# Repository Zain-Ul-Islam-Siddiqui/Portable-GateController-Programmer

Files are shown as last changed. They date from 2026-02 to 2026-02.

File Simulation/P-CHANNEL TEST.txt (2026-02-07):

$ 1 0.000005 10.20027730826997 50 5 43 5e-11
f 400 240 448 240 33 1.5 0.02
r 448 160 448 112 0 470
r 384 192 432 192 0 1000000
r 256 240 208 240 0 2200
s 336 208 336 160 0 1 false
s 96 320 96 272 0 1 false
r 96 208 96 160 0 100000
R 96 112 96 80 0 0 40 3.3 0 0 0.5
R 336 112 336 80 0 0 40 3.3 0 0 0.5
w 96 112 96 160 0
w 448 288 448 256 0
w 448 192 448 224 0
w 336 160 336 144 0
w 336 144 336 112 0
g 320 352 320 368 0 0
g 448 352 448 368 0 0
g 96 352 96 368 0 0
w 96 352 96 320 0
w 320 352 320 304 0
w 448 352 448 288 0
w 384 192 384 240 0
w 432 192 448 192 0
w 448 192 448 160 0
w 448 80 448 112 0
s 320 304 320 256 0 1 false
w 320 256 320 240 0
w 336 208 336 240 0
162 400 80 448 80 2 default-led 1 0 0 0.01
R 400 80 400 48 0 0 40 5 0 0 0.5
w 384 240 400 240 0
w 336 240 384 240 0
w 336 240 320 240 0
w 256 240 320 240 0
w 96 208 96 240 0
w 96 240 208 240 0
w 96 272 96 240 0

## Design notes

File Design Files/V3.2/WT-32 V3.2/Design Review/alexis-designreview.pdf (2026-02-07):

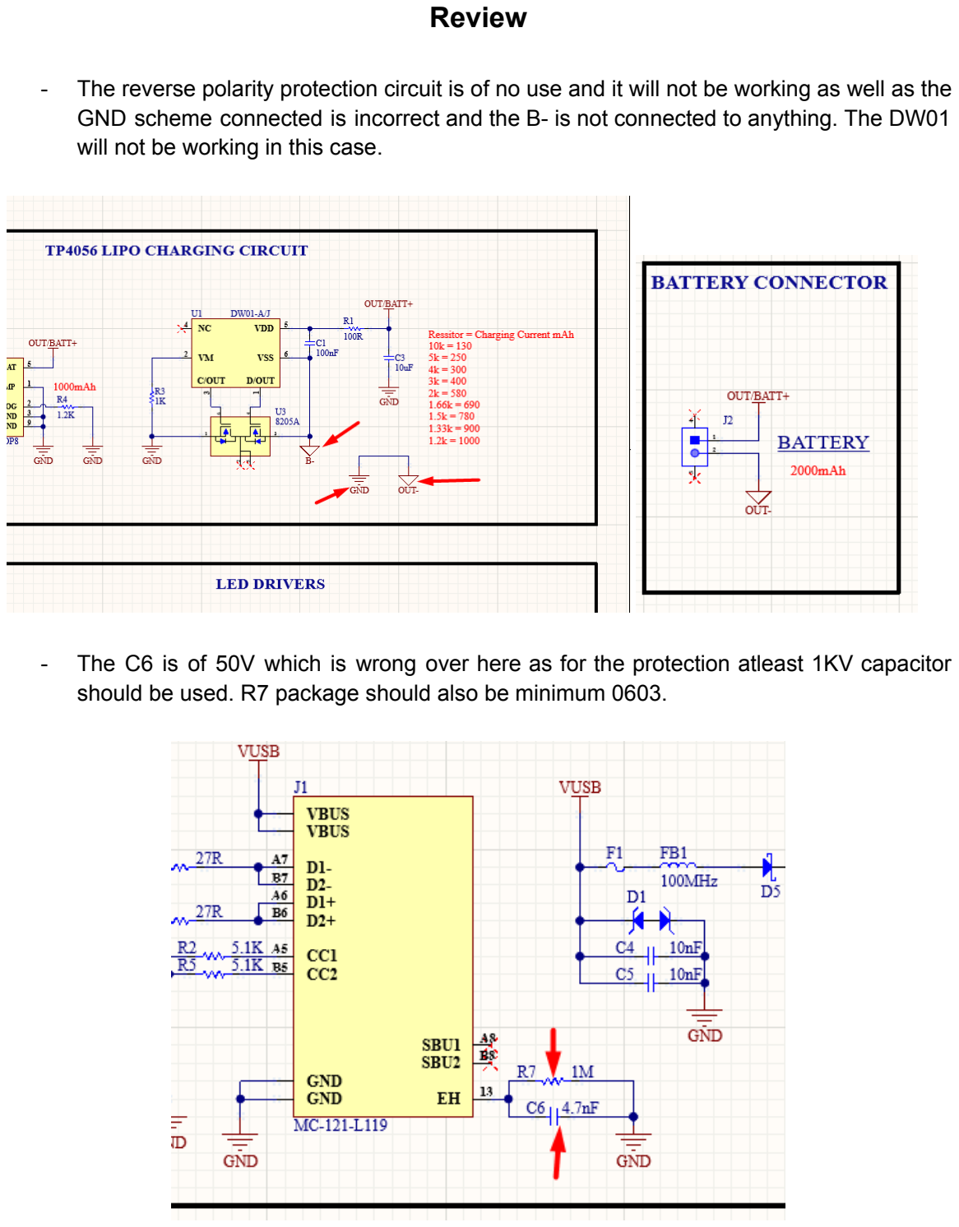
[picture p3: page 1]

### Review

- The reverse polarity protection circuit is of no use and it will not be working as well as the GND scheme connected is incorrect and the B- is not connected to anything. The DW01 will not be working in this case.
- The C6 is of 50V which is wrong over here as for the protection atleast 1KV capacitor should be used. R7 package should also be minimum 0603.

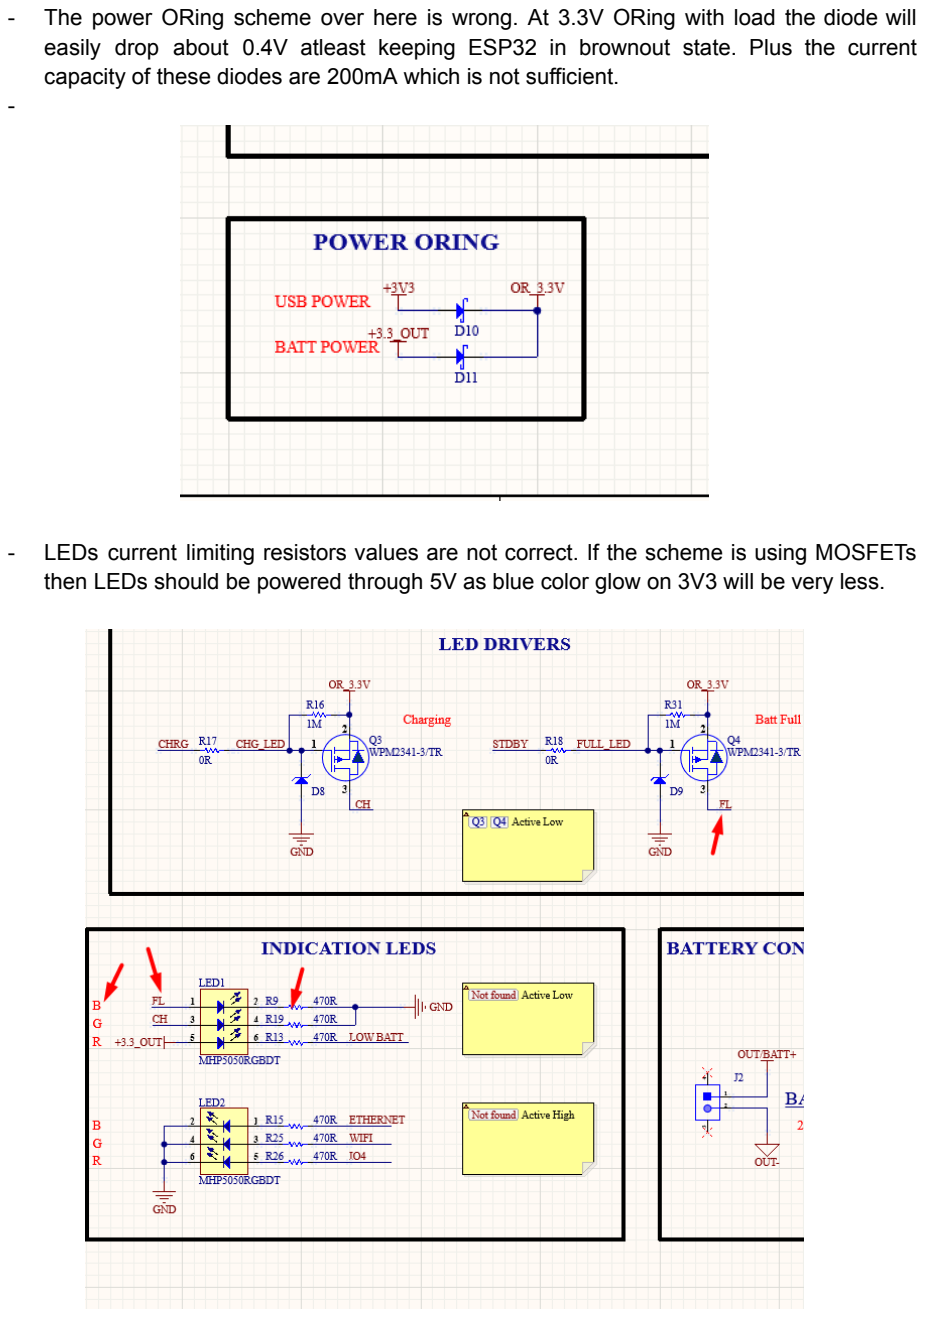
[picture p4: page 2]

- The power ORing scheme over here is wrong. At 3.3V ORing with load the diode will easily drop about 0.4V atleast keeping ESP32 in brownout state. Plus the current capacity of these diodes are 200mA which is not sufficient.
- LEDs current limiting resistors values are not correct. If the scheme is using MOSFETs then LEDs should be powered through 5V as blue color glow on 3V3 will be very less.

- Please confirm the battery connector pinout is correct as generally pin 1 is connected to GND.

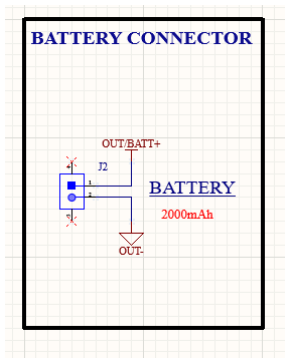
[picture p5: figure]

- Low battery cutoff might not be needed as we are using Fuel Gauge in this design. Even for the overdischarge protection, DW01 is already implemented.

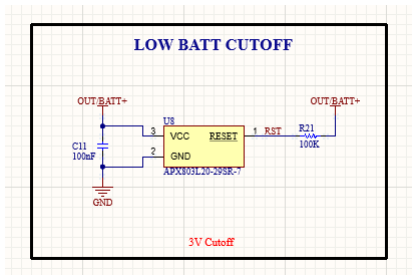
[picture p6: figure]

- C26 should not be used on IO0 as it will fail the USB auto download functionality.

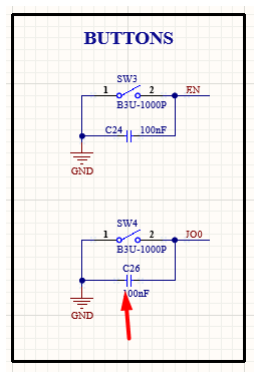
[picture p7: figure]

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
s it is

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
pin.

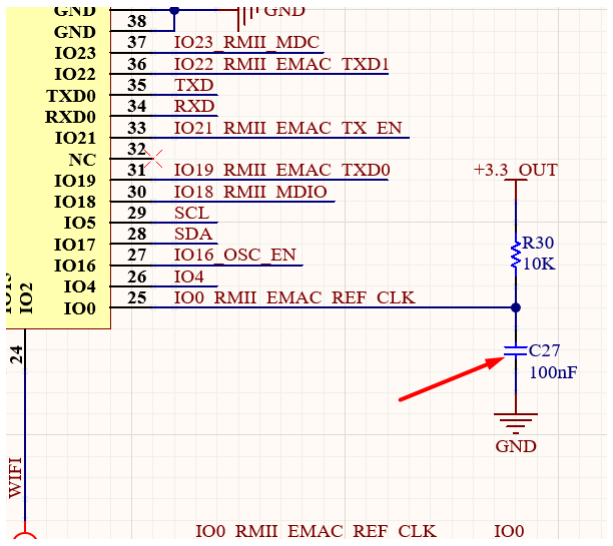
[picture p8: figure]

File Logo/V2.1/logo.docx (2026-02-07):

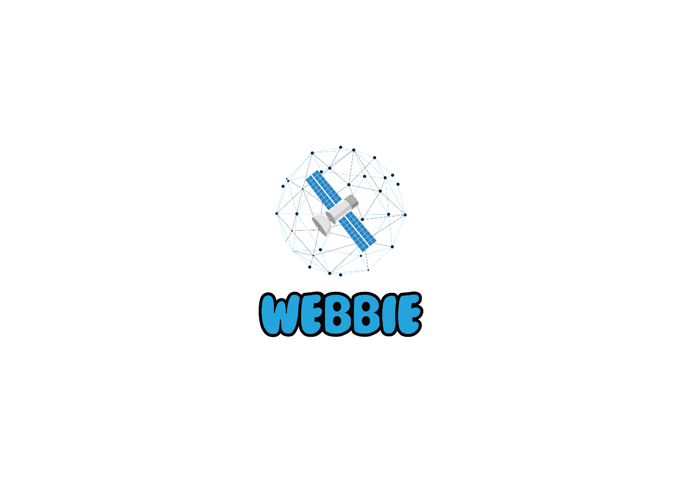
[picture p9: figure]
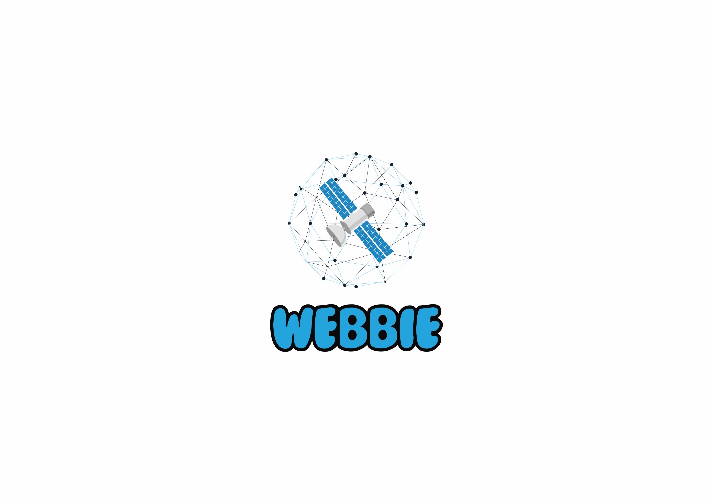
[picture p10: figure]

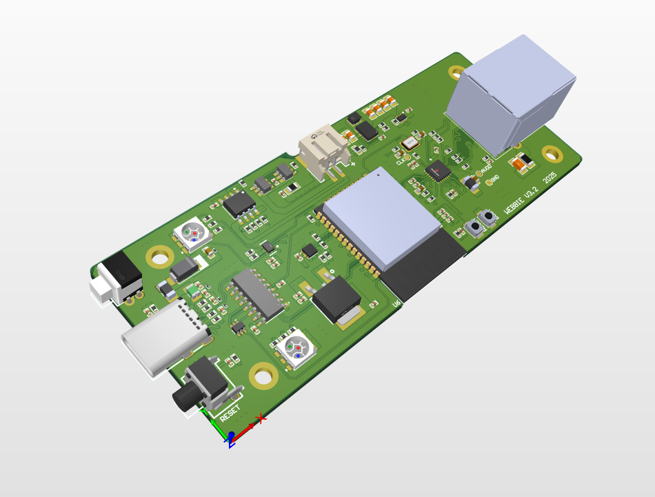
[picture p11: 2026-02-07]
Design Files/V3.2/WT-32 V3.2/Rendering/3D Isometric.png

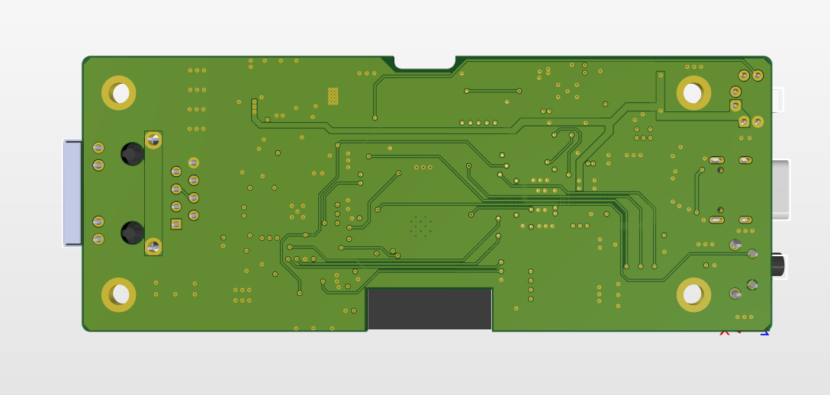
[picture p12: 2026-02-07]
Design Files/V3.2/WT-32 V3.2/Rendering/3D Bottom.png

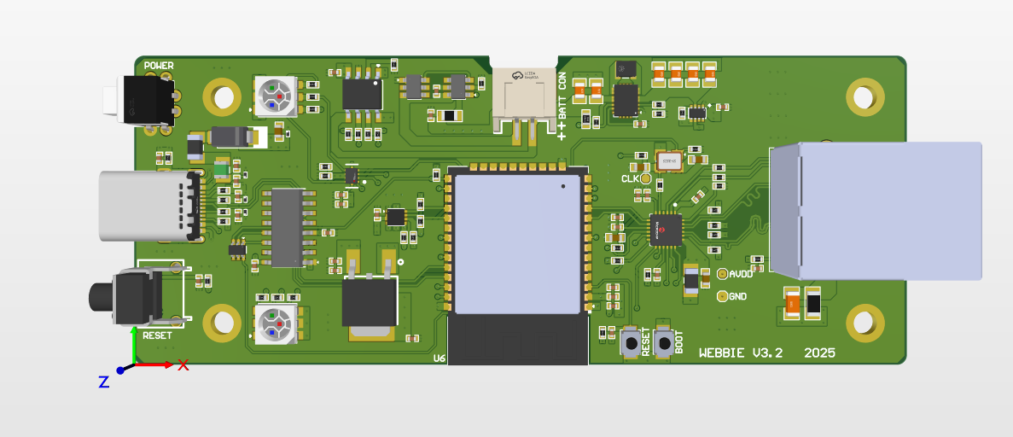
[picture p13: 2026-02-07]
Design Files/V3.2/WT-32 V3.2/Rendering/3D Top.png

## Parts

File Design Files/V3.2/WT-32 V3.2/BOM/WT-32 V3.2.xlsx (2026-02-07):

Designator | Comment | Footprint | LCSC Part Number | Manufacturer Part Number
C1, C2, C9, C10, C20, C22, C23, C24, C29, C31, C34, C35, C36, C41, C43 | 100nF | cap-0402 | C361198 | C1005X7R1H104KT000F
C3 | 10uF | Cap-0402 | C315248 | CL05A106MP5NUNC
C4, C5, C21, C28 | 10nF | Cap-0402 | C327025 | CC0402KRX7R8BB103
C6, C33, C39 | 4.7nF | Cap-0402 | C106208 | CC0402KRX7R9BB472
C7, C8, C11, C27, C32 | 1uF | Cap-0402 | C106254, C326568, C325464 | CC0402KRX5R6BB105, CC0402KRX5R8BB105, CC0402KRX5R7BB105
C12, C26, C30, C37 | 10uF | Cap-0603 | C96446 | CL10A106MA8NRNC
C13, C14 | 47pF | Cap-0402 | C393684 | GCM1555C1H470FA16D
C15, C16, C17, C18, C19, C25 | 22uF | Cap-0805 | C338080 | C2012X5R1V226MT000E
C40 | 4.7nF | Cap-1206 | C107198 | CC1206KKX7RCBB472
D1, D4, D6, D7 | PESD5V0H1BSFYL | DSN0603-2 | C477989 | PESD5V0H1BSFYL
D5 | SS34 | SMA | C8678 | SS34
F1 | BSMD0805L-200 | Fuse-0805 | C2757931 | BSMD0805L-200
FB1, FB2 | 100MHz | IND-1206 | C85841 | BLM31PG121SN1L
J1 | MC-121-L119 | MC-121-L119 | C6332278 | MC-121-L119
J2 | S2B-PH-SM4-TB(LF)(SN) | S2B-PH-SM4-TB(LF)(SN) | C295747 | S2B-PH-SM4-TB(LF)(SN)
J3 | HR911105A | HR911105A | C12074 | HR911105A
L1 | 1uH | IND-1008 (2520 Metric) | C882955 | DFE252012P-1R0M=P2
LED1, LED2 | MHP5050RGBDT | MHP5050RGBDT | C409780 | MHP5050RGBDT
R1 | 100R | RES-0805 | C138274 | AC0805FR-07100RL
R2, R5 | 5.1K | Res-0402 | C105872 | RC0402FR-075K1L
R3 | 1K | Res-0402 | C313354 | CRCW04021K00FKEDHP
R4 | 1.2K | Res-0402 | C138040 | RC0402FR-071K2L
R6, R8, R17, R18, R20, R21, R27, R30, R32, R33, R37, R39, R45, R49, R50 | 10K | Res-0402 | C60490 | RC0402FR-0710KL
R7 | 1M | Res-0402 | C144054 | AF0402JR-071ML
R9, R13, R15, R19, R25, R26, R40, R42 | 470R | Res-0402 | C114877 | RC0402FR-07470RL
R10, R11, R44 | 0R | Res-0402 | C106231 | RC0402FR-070RL
R14 | 768k | Res-0402 | C227223 | AC0402FR-07768KL
R16 | 10K | Res-0603 | C95204 | RT0603BRD0710KL
R22, R23 | 27R | Res-0402 | C138021 | RC0402FR-0727RL
R24 | 137k | Res-0402 | C5153963 | FRC0402F1373TS
R28, R29, R34, R35 | 49.9R | Res-0402 | C87044 | RC0402FR-0749R9L
R36 | 1.5K | Res-0402 | C114759 | RC0402FR-071K5L
R38, R41 | 33R | Res-0402 | C138002 | RC0402FR-0733RL
R43 | 12.1k | Res-0402 | C281773 | RT0402BRD0712K1L
R46 | 1M | Res-1206 | C108083 | RC1206FR-071ML
SW1 | TK-6580A8-1 | TK-6580A8-1 | C528772 | TK-6580A8-1
SW2 | 1-1825027-4 | 1-1825027-4 | C2928195 | 1-1825027-4
SW3, SW4 | B3U-1000P | B3U-1000P | C231329 | B3U-1000P
U1 | DW01-A/J | SOT-23-6 | C2909013 | DW01-A/J
U2 | TP4056-42-ESOP8 | ESOP-8 | C16581 | TP4056-42-ESOP8
U3 | 8205A | SOT-23-6 | C351449 | 8205A
U4 | UZ1085L-33-TN3-R | TO-252-2(DPAK) | C125622 | UZ1085L-33-TN3-R
U5 | TPS63020DSJR | 14-VSON (4x3) | C15483 | TPS63020DSJR
U6 | ESP32-WROOM-32E-N4 | 38-SMD Module | C701341 | ESP32-WROOM-32E-N4
U7 | UMH3N | SC-70-6_ | C62892 | UMH3N
U8 | LM66200DRLR | SOT8 | C3235556 | LM66200DRLR
U9 | CH340C | SOP-16 | C84681 | CH340C
U10 | LAN8720A-CP-TR | LAN8720A-CP-TR | C45223 | LAN8720A-CP-TR
U11 | MAX17048G+T10 | 8-TDFN-EP (2x2) | C2682616 | MAX17048G+T10
U12 | TS3A24157RSER | UQFN-10(1.5x2) | C575568 | TS3A24157RSER
X1 | 50MHz | OT2EL4C4JI-111OLP-50M | C5203552 | OT2EL4C4JI-111OLP-50M

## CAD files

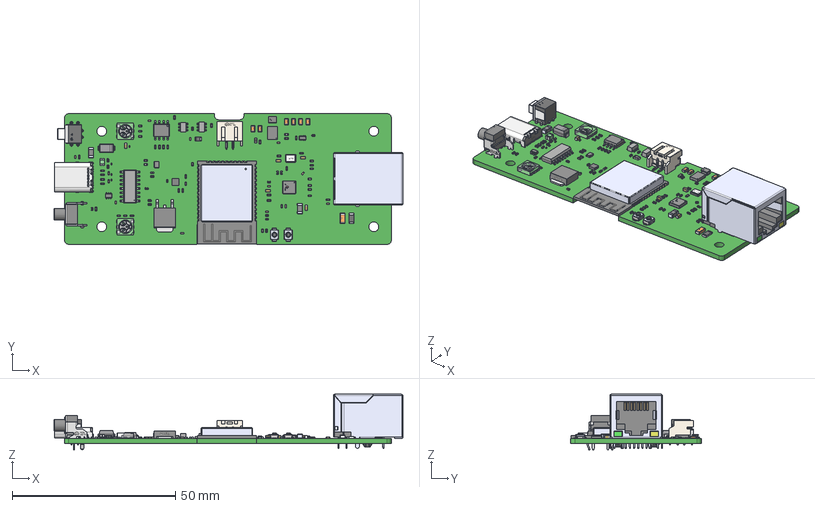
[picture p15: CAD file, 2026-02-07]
Design Files/V3.2/WT-32 V3.2/STEP 3D/Webbie-V3.2.step
106.8 x 40.0 x 17.0 mm
q3yF-Board
HR911105A_HR911105A
User Library-User Library-Siward_SX3225
Texas Logo Yury
Texas Logo Yury - Copy
21-0168E_T822-1_MXM
pads
Microchip logo
Microchip Logo 1
SO_18HDTR_STM
User Library-SC70-6
TPS63020DSJR--3DModel-STEP-1
21-0058I_MXM x 2
TP4056-42-ESOP8--3DModel-STEP-56544
User Library-OMRON B3U1000P x 2
User Library-RES_1005-0402 x 44
User Library-RESC1608X05N
User Library-CR3216-1206
User Library-CR2012-0805
LED SMD 5050 RGB x 2
VLS252012HBX-100M
BLM31PG121SN1L x 2
User Library-fuse0805L050WR
PESD5V0H1BSF x 4
User Library-DO-214AC SMA
User Library-Capacitor 0402 x 30
User Library-0805 SMD Capacitor x 6
User Library-1206 SMD Capacitor
User Library-CAPC1608X09 x 5
ESP32-WROOM-32E (16MB)--3DModel-STEP-269445
aZC3-SW1-SW-TH_1-1825027-4

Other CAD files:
Design Files/V3.2/WT-32 V3.2/DXF/Webbie-V3.0.DXF

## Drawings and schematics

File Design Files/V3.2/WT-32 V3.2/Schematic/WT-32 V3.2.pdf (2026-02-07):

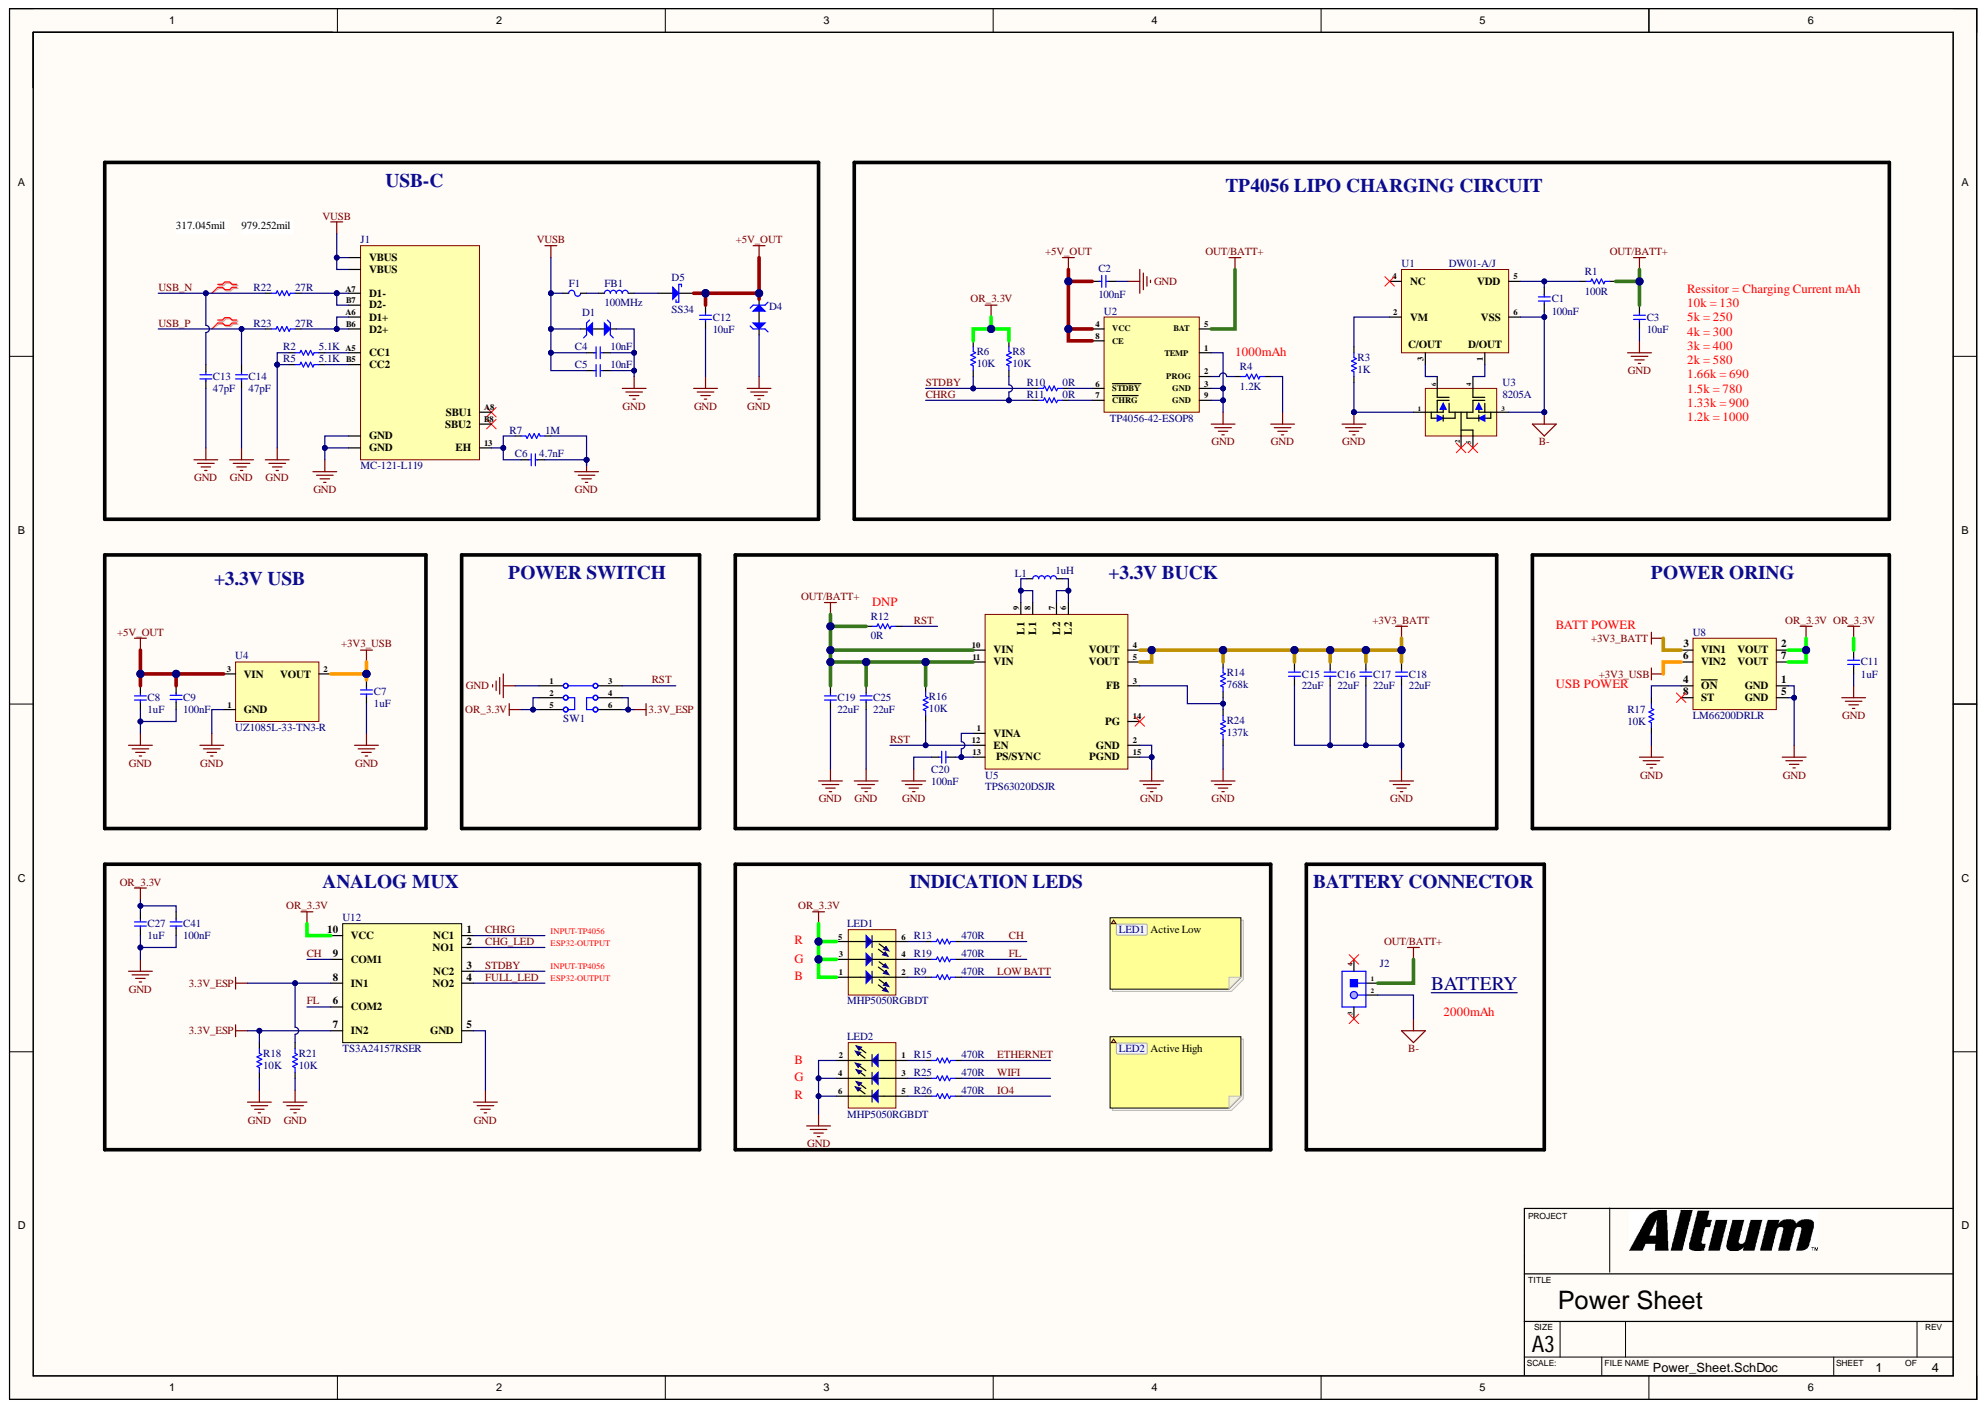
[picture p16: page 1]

SIZE | | | REV

SCALE: | FILE NAME | SHEET OF

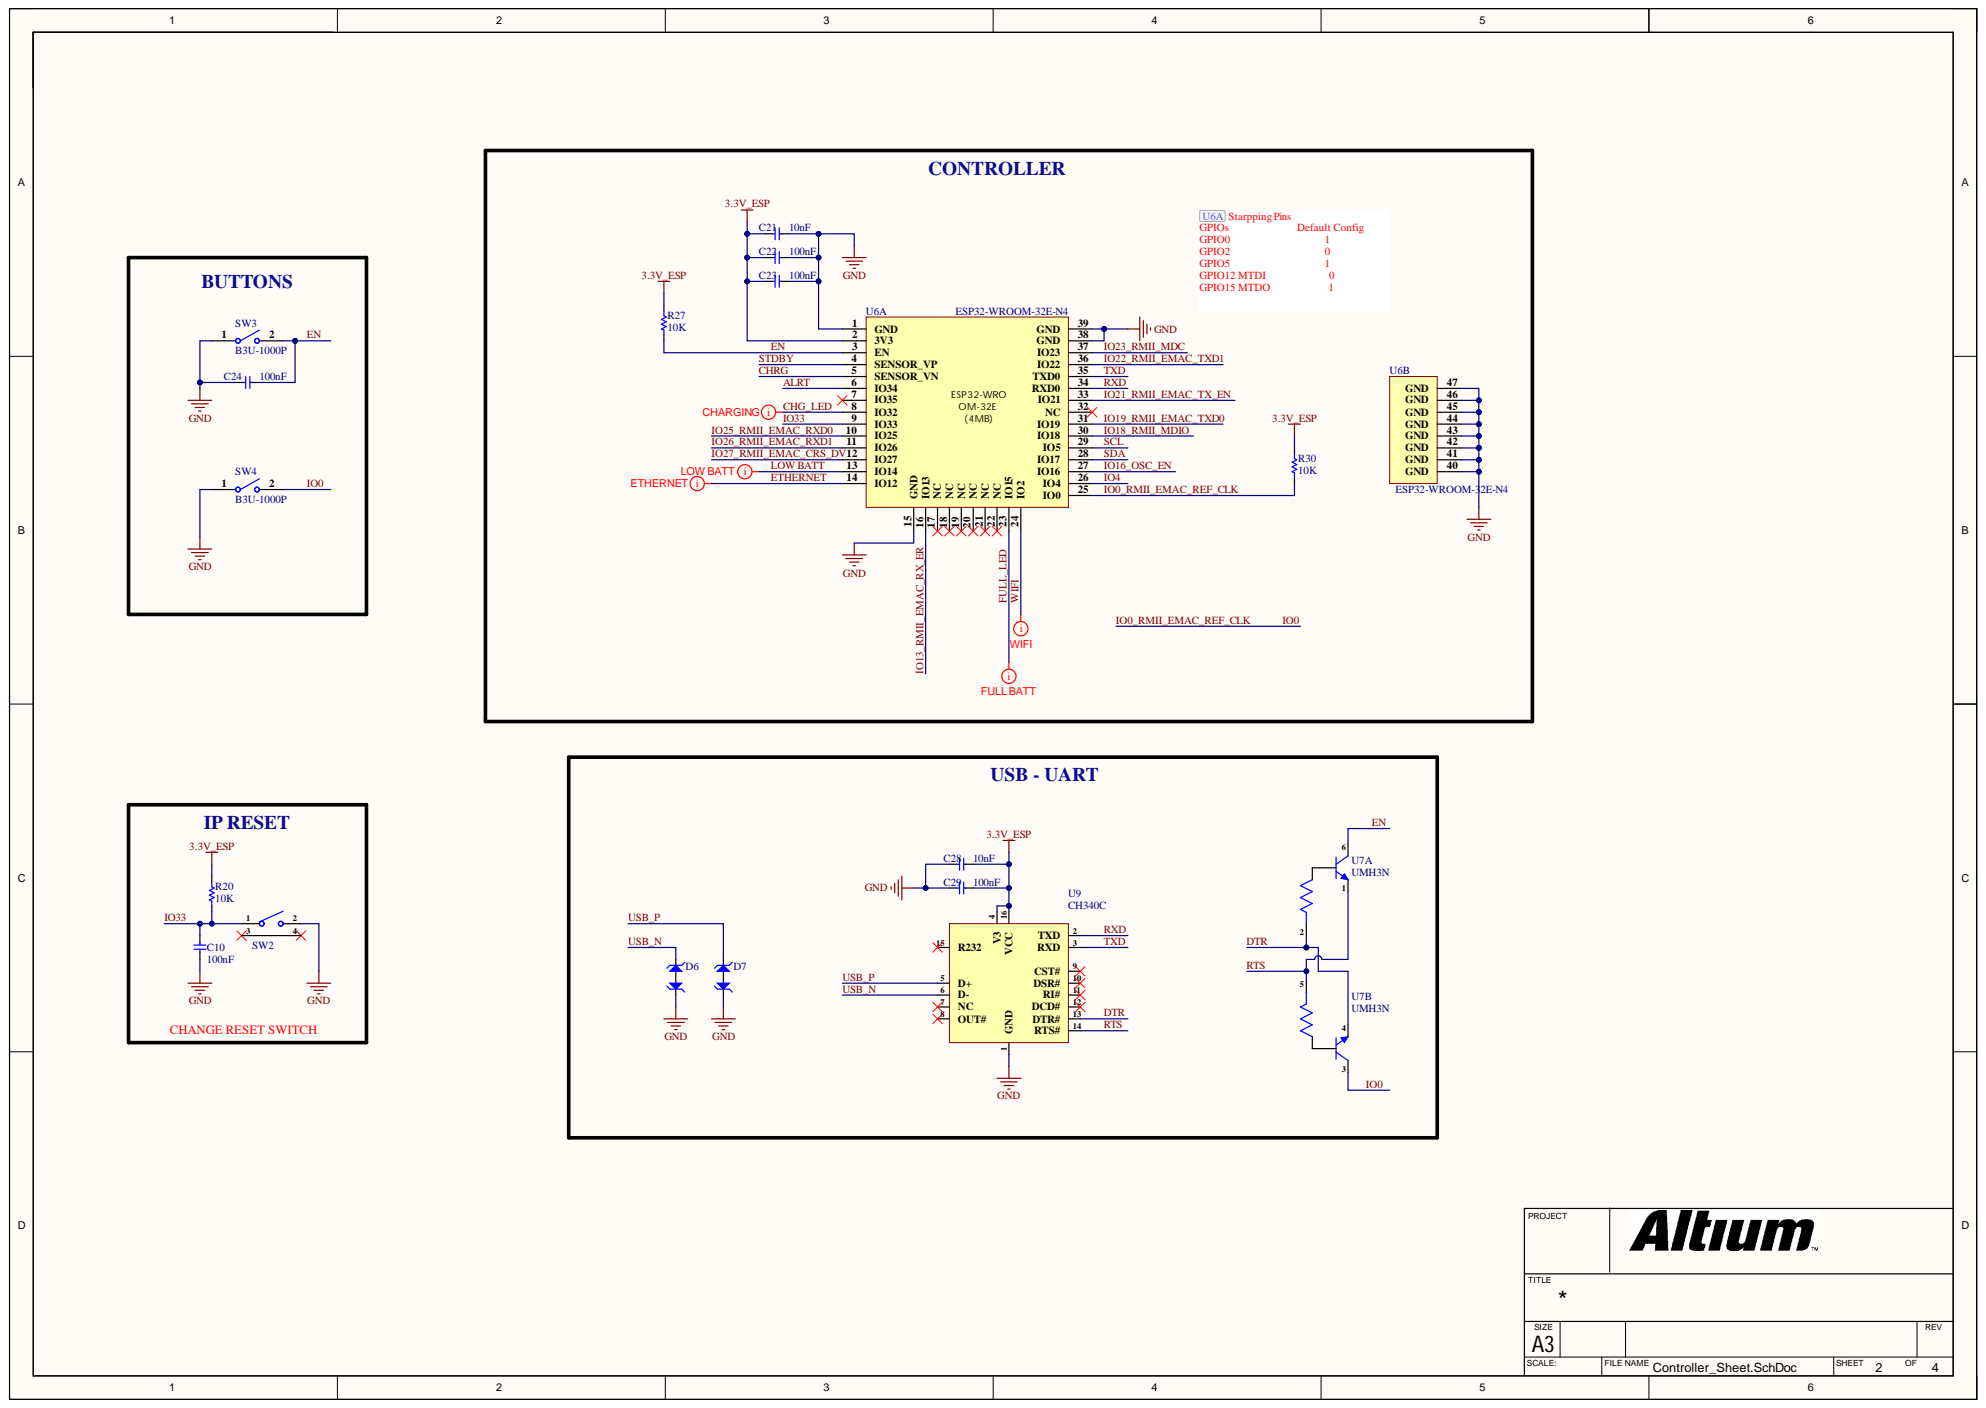
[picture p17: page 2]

GN D GN 3V3 EN SENSOR_V P SENSOR_V N IO3 4 IO3 5 E S P 3 2-WR O O M -32E IO3 2 IO3 3 ( 4 M B ) 5 10 IO2 IO2 6 7 12 IO2 4 13 IO1 2 14 IO1 | XD 1
2 | | IO23_RMII_M TX D

IO0_RMII_EMAC_REF_ CLK

SIZ E | | | RE V

SCA L E : | FIL E NA M E ntro l l er_Sh e et.Sc h D o c | SHE E T OF

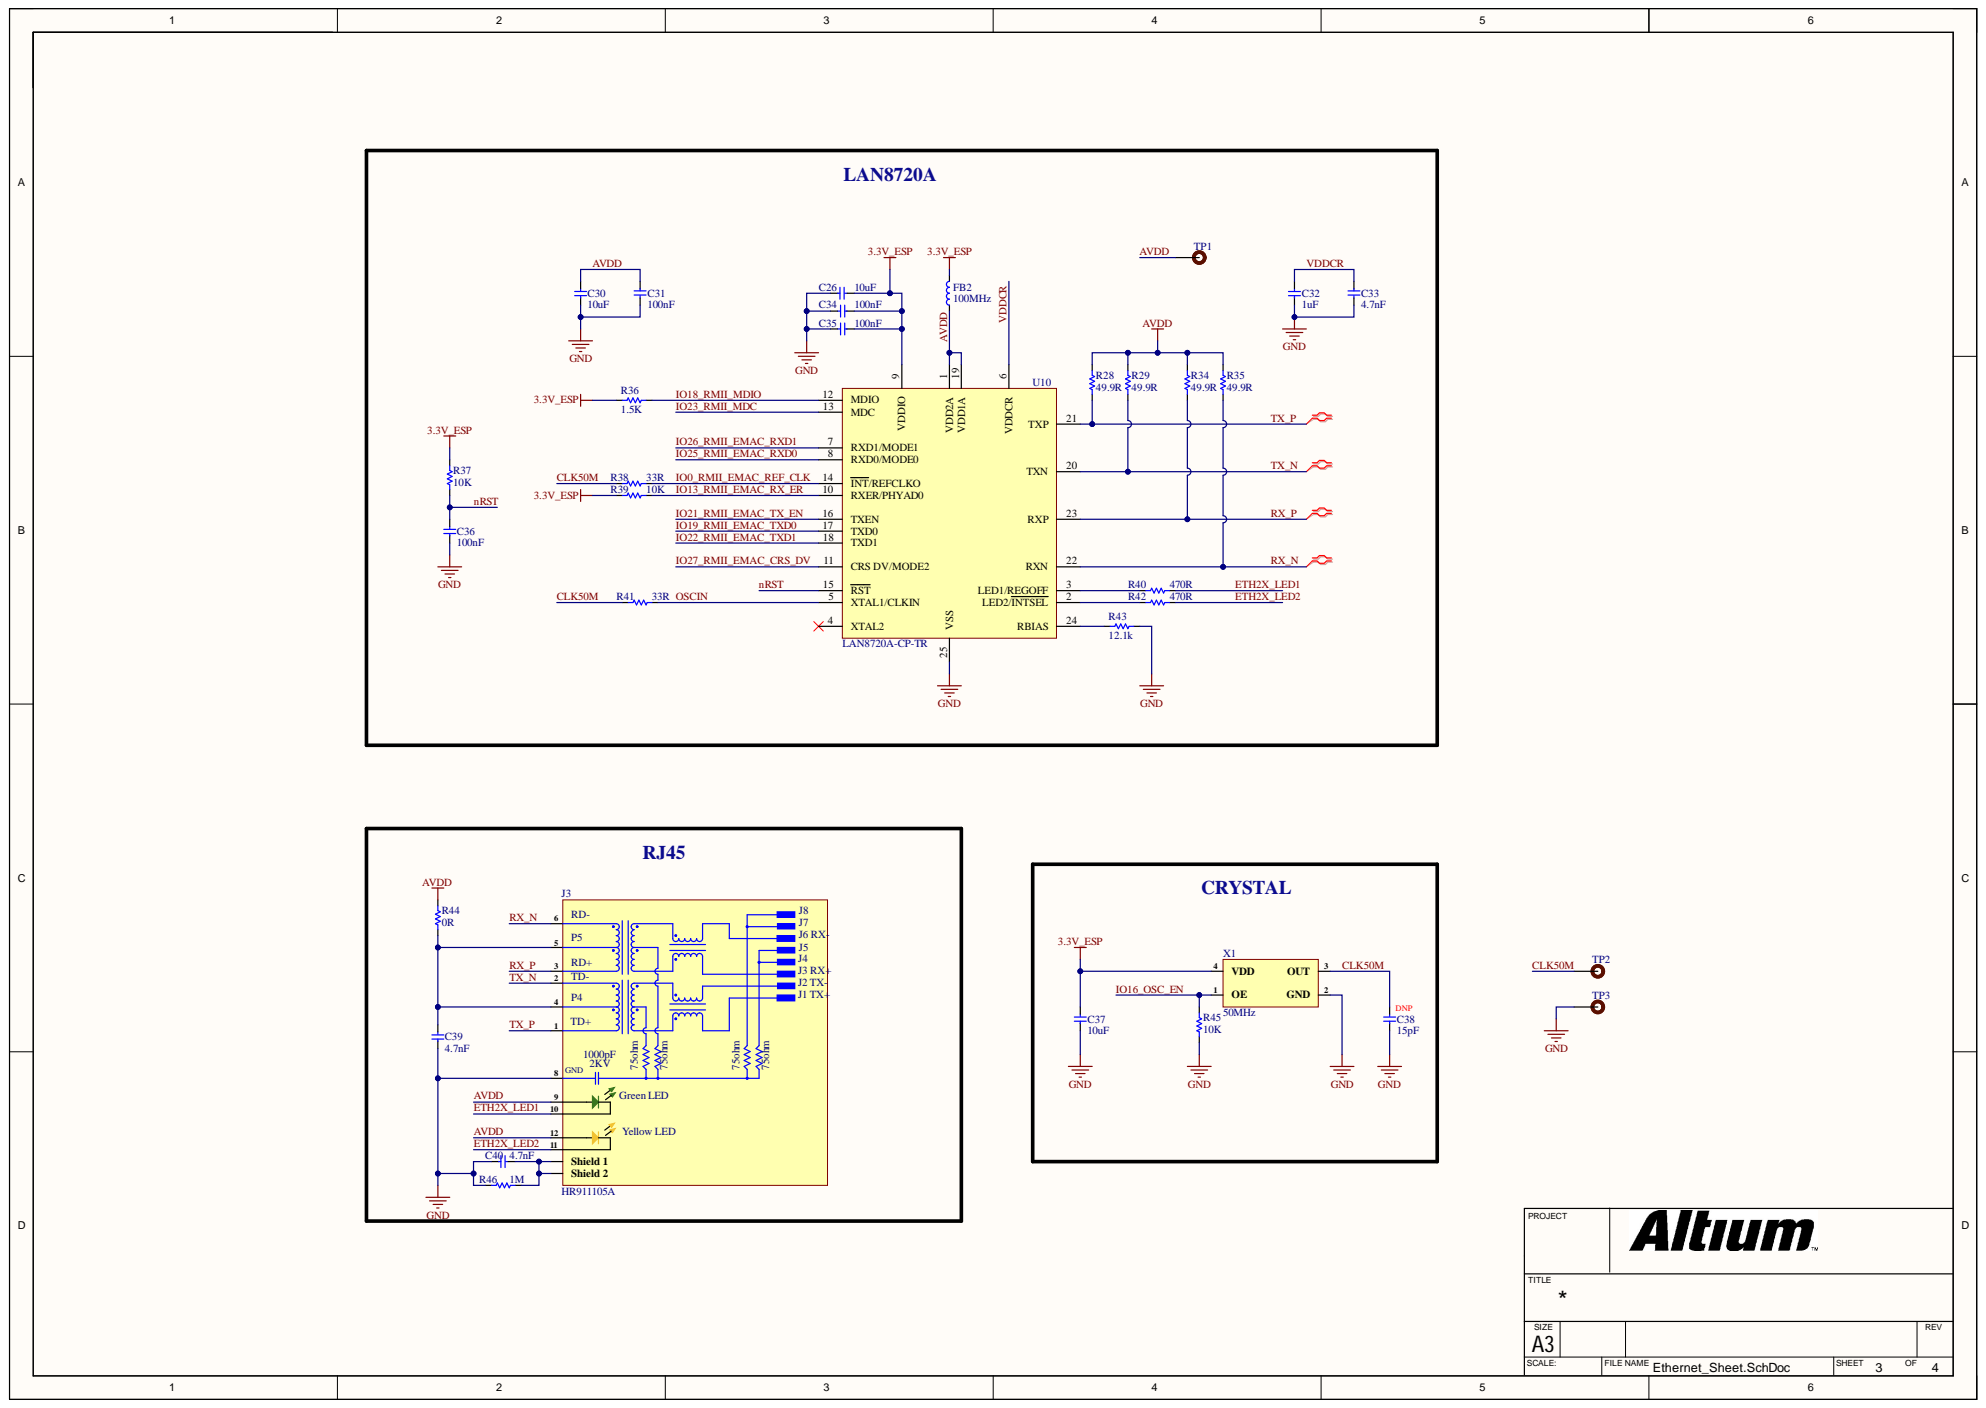
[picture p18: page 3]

Shield 1 Shield 2

SIZE | | | REV

SCALE: | FILE NAME | SHEET OF

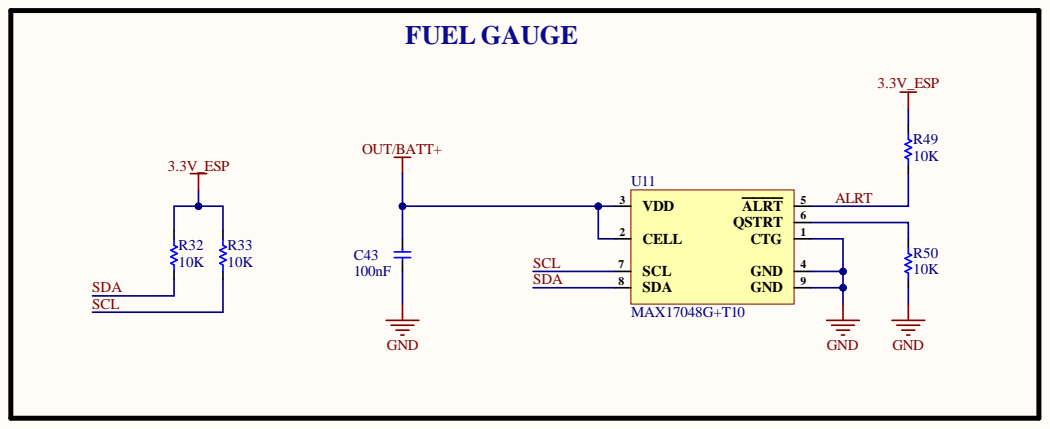
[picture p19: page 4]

SIZ E | | | RE V

SCA L E : | FIL E NA M E e l G a u g e _Sh e et.Sc h D o c | SHE E T OF

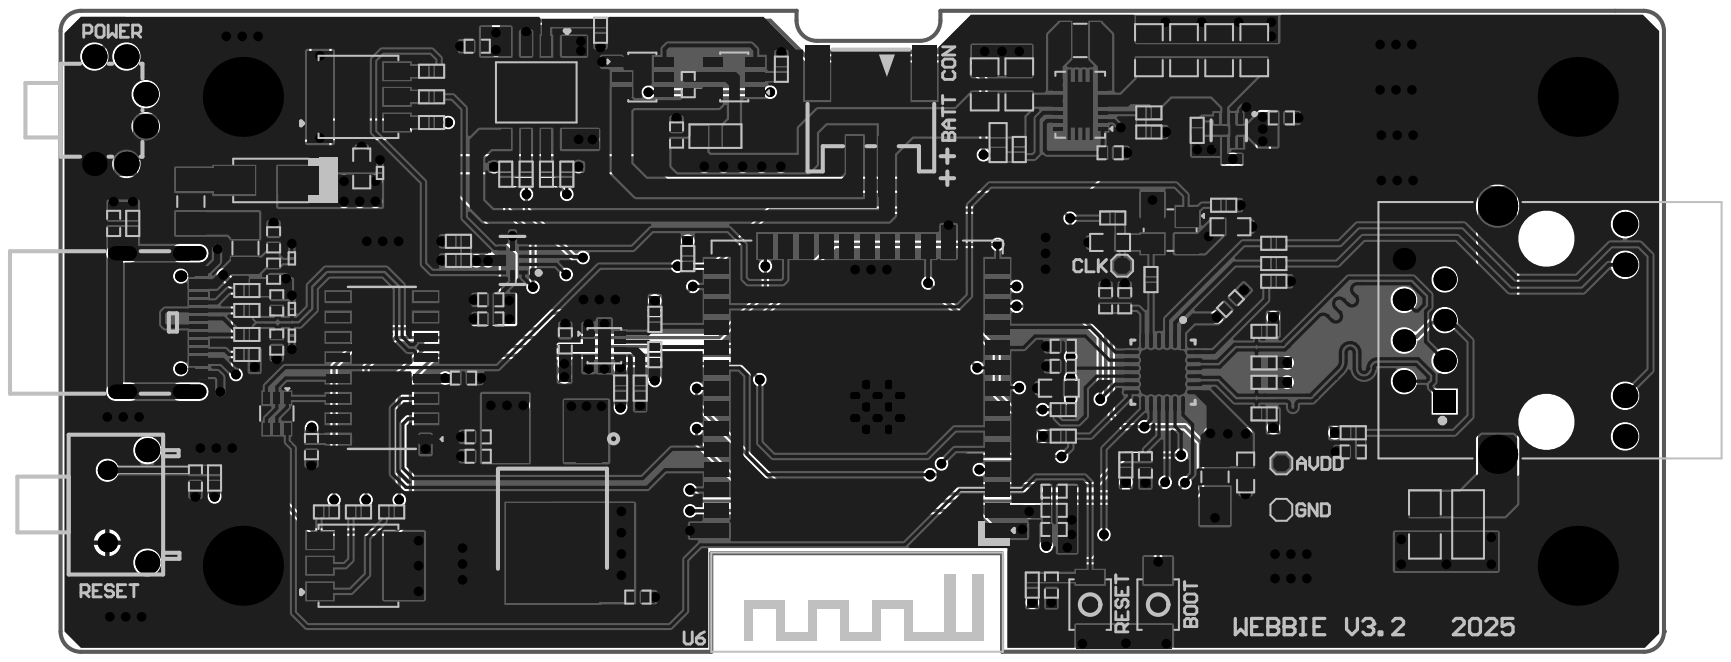
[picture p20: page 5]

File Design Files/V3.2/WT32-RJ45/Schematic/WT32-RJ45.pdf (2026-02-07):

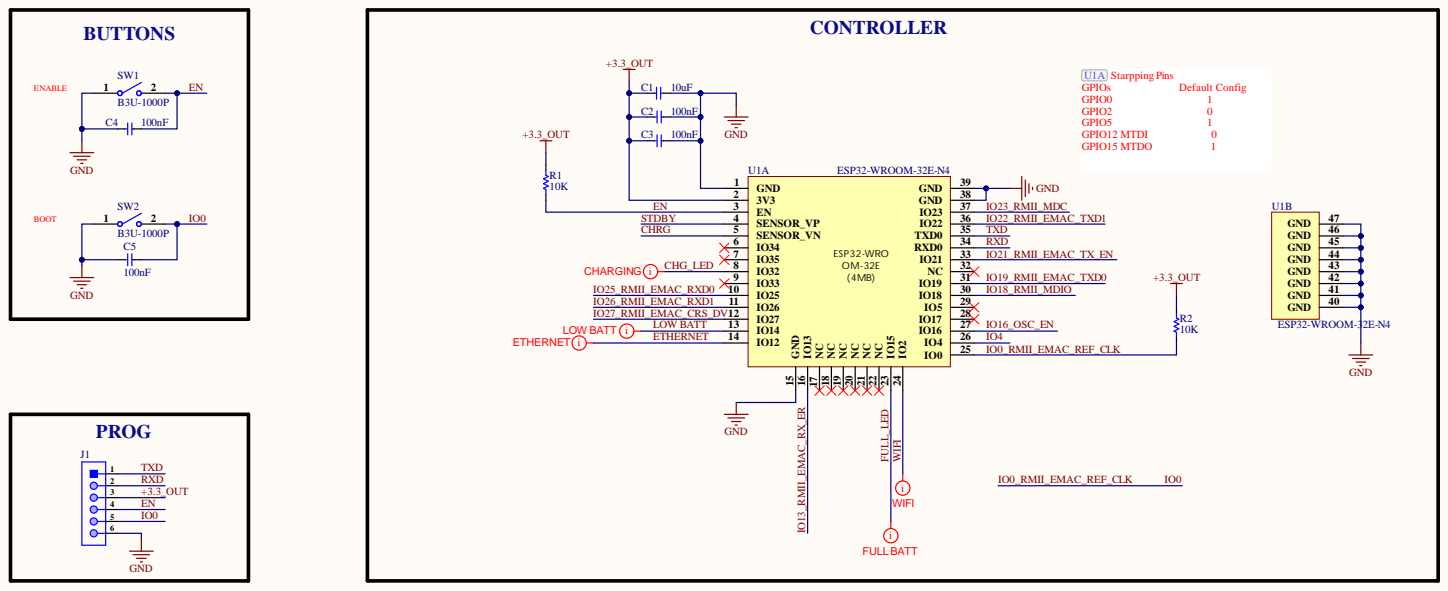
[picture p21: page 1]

2 | | IO23_RMII_M

SIZ E | | | RE V

SCA L E : | FIL E NA M E 2.Sc hDo c | SHE E T OF

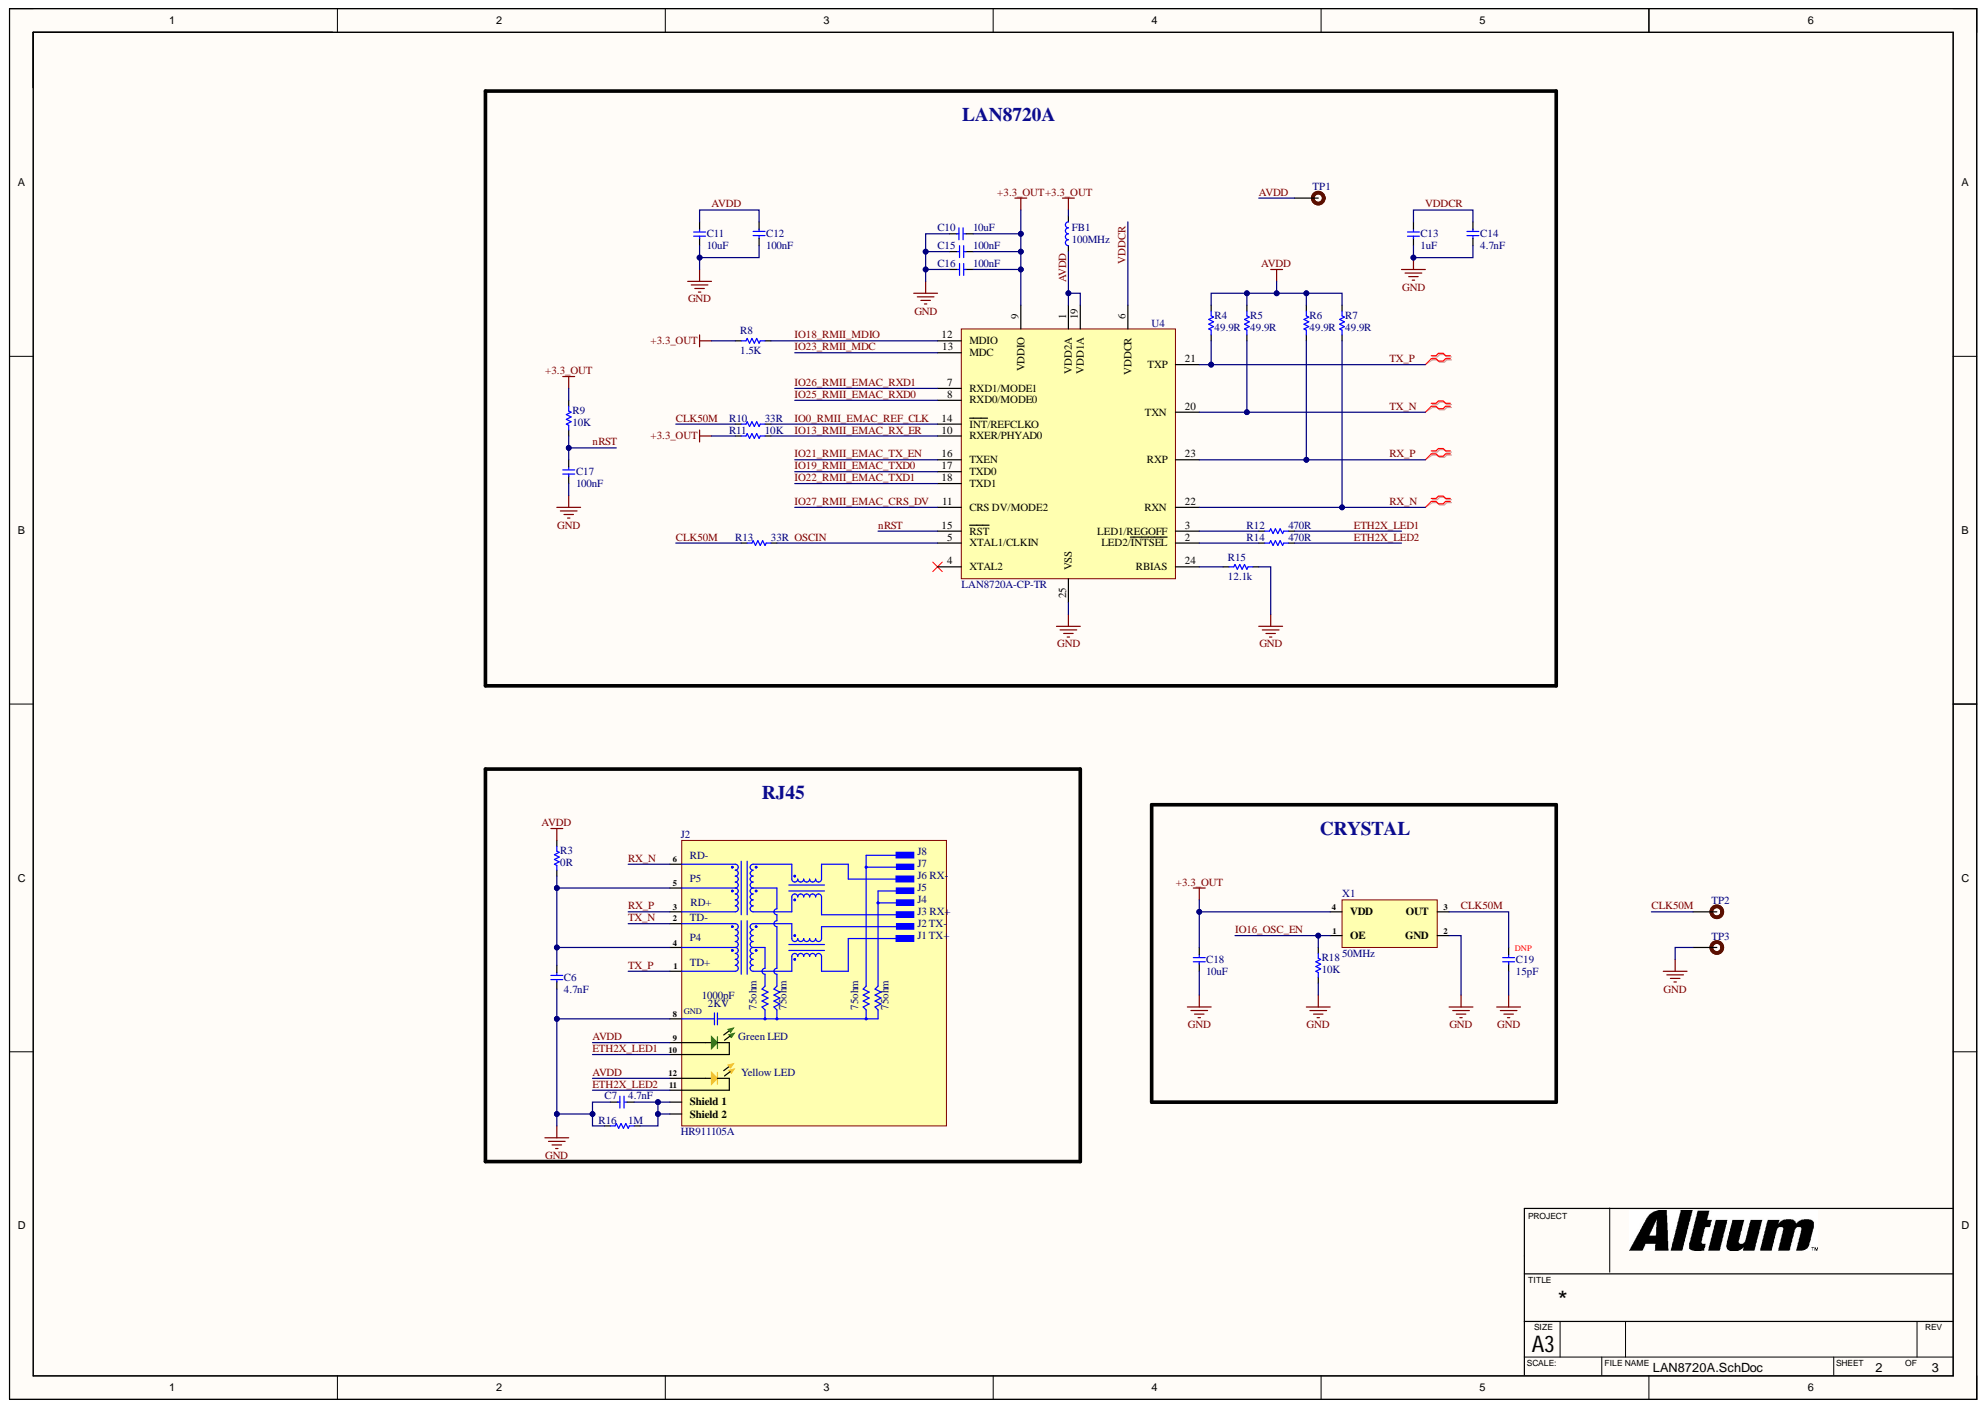
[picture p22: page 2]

SIZE | | | REV

SCALE: | FILE NAME | SHEET OF

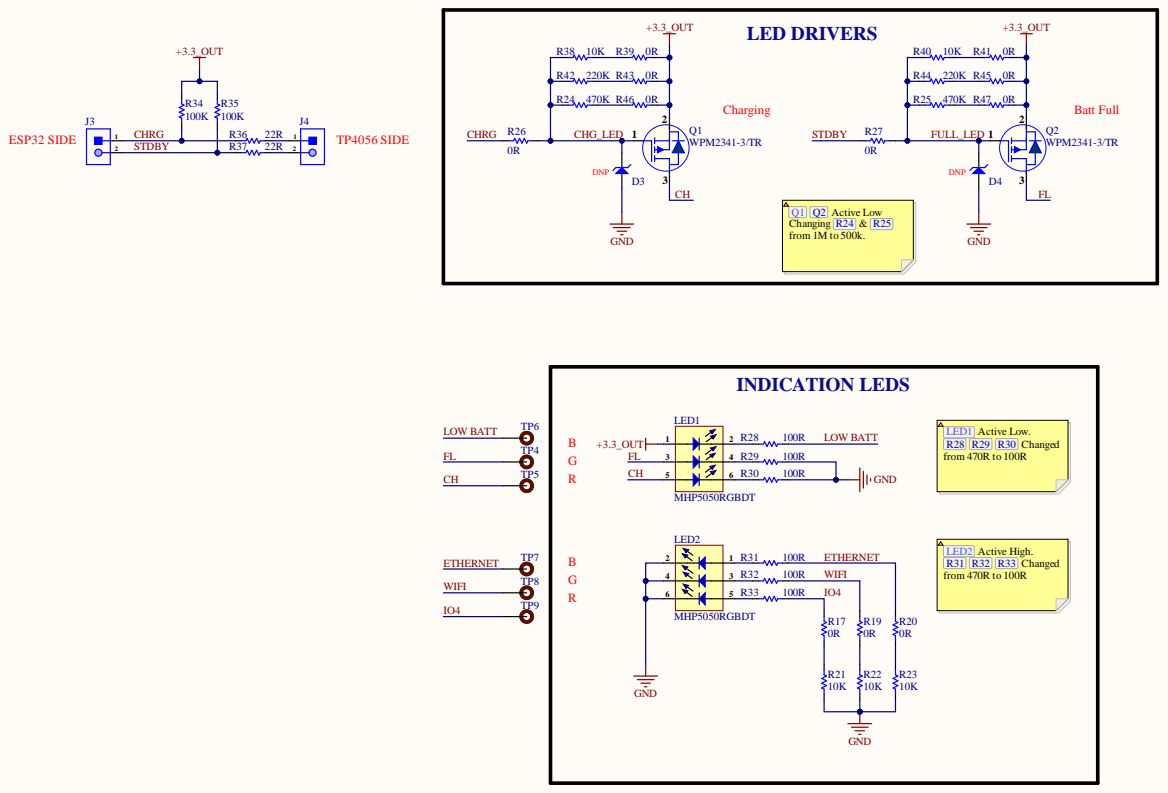
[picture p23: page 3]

SIZE | | | REV

SCALE: | FILE NAME | SHEET OF

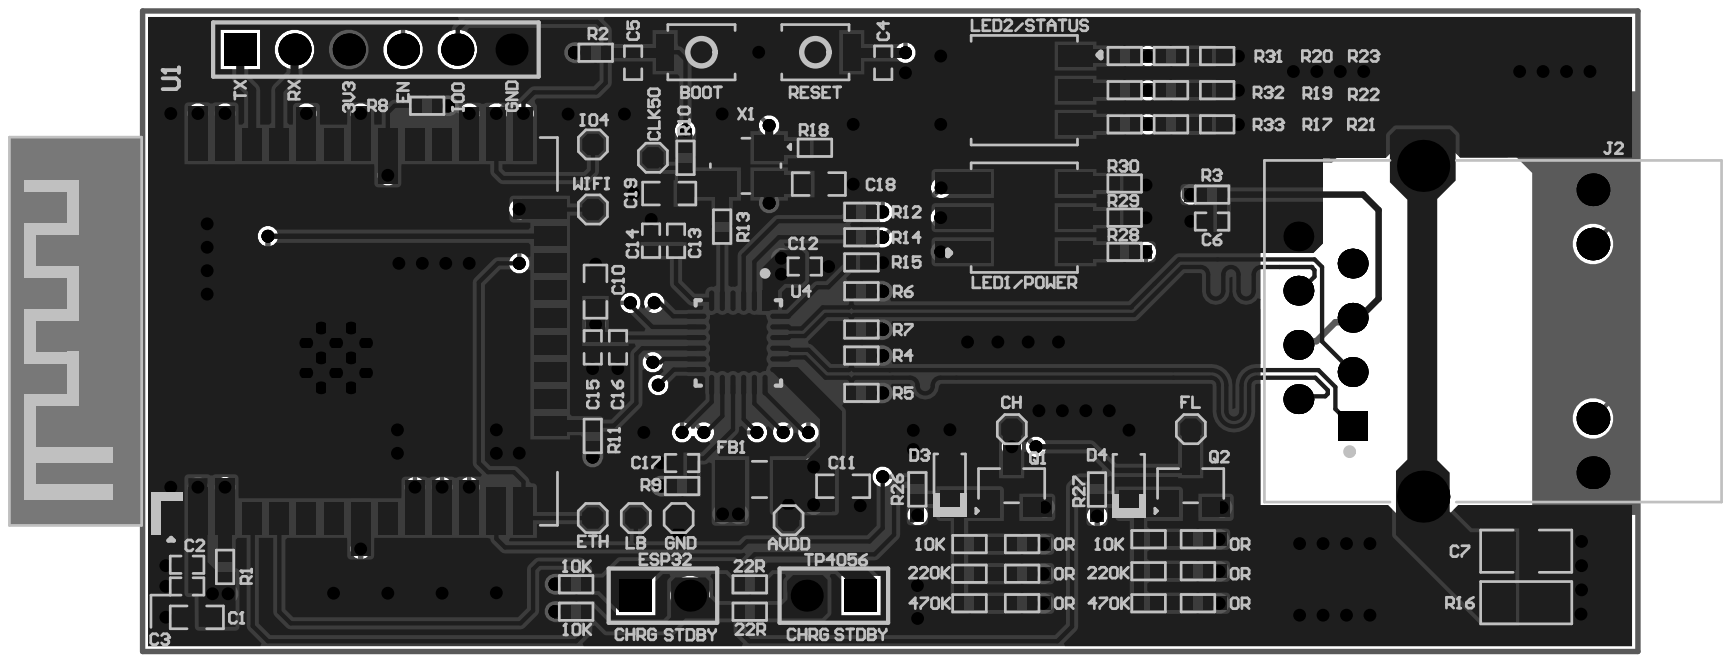
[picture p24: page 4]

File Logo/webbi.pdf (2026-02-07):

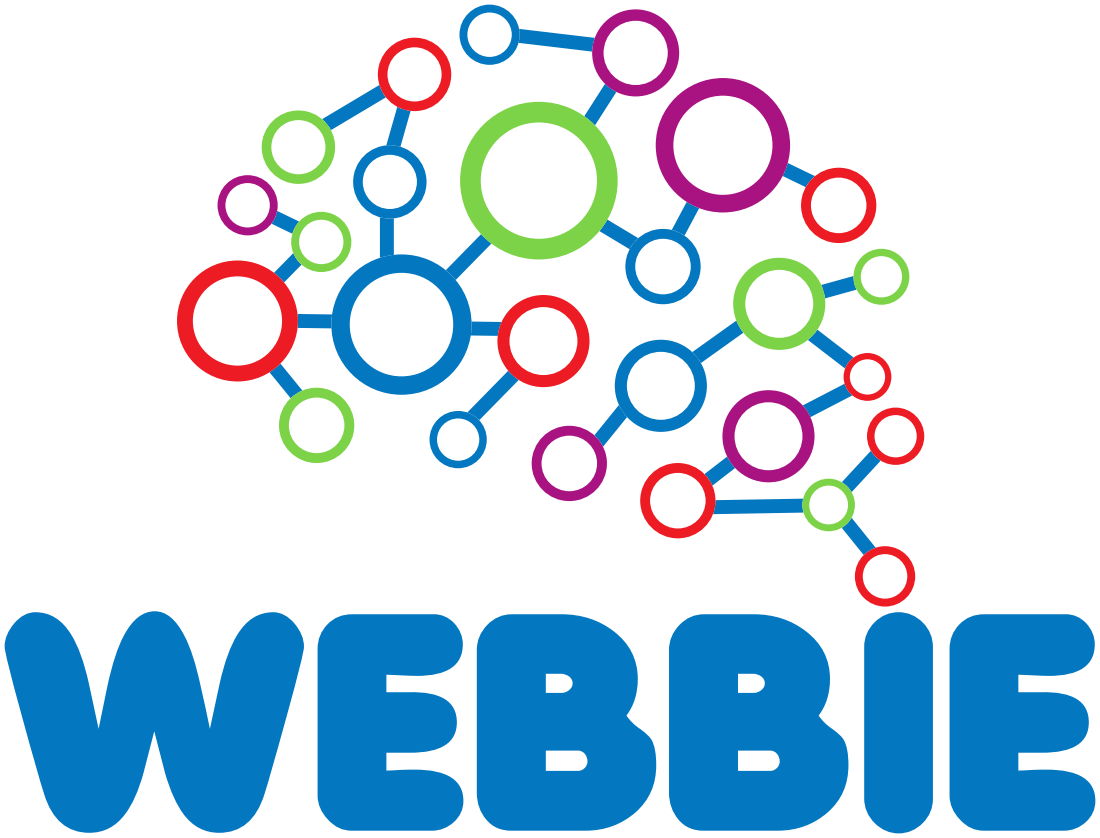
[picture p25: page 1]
WEBBIE

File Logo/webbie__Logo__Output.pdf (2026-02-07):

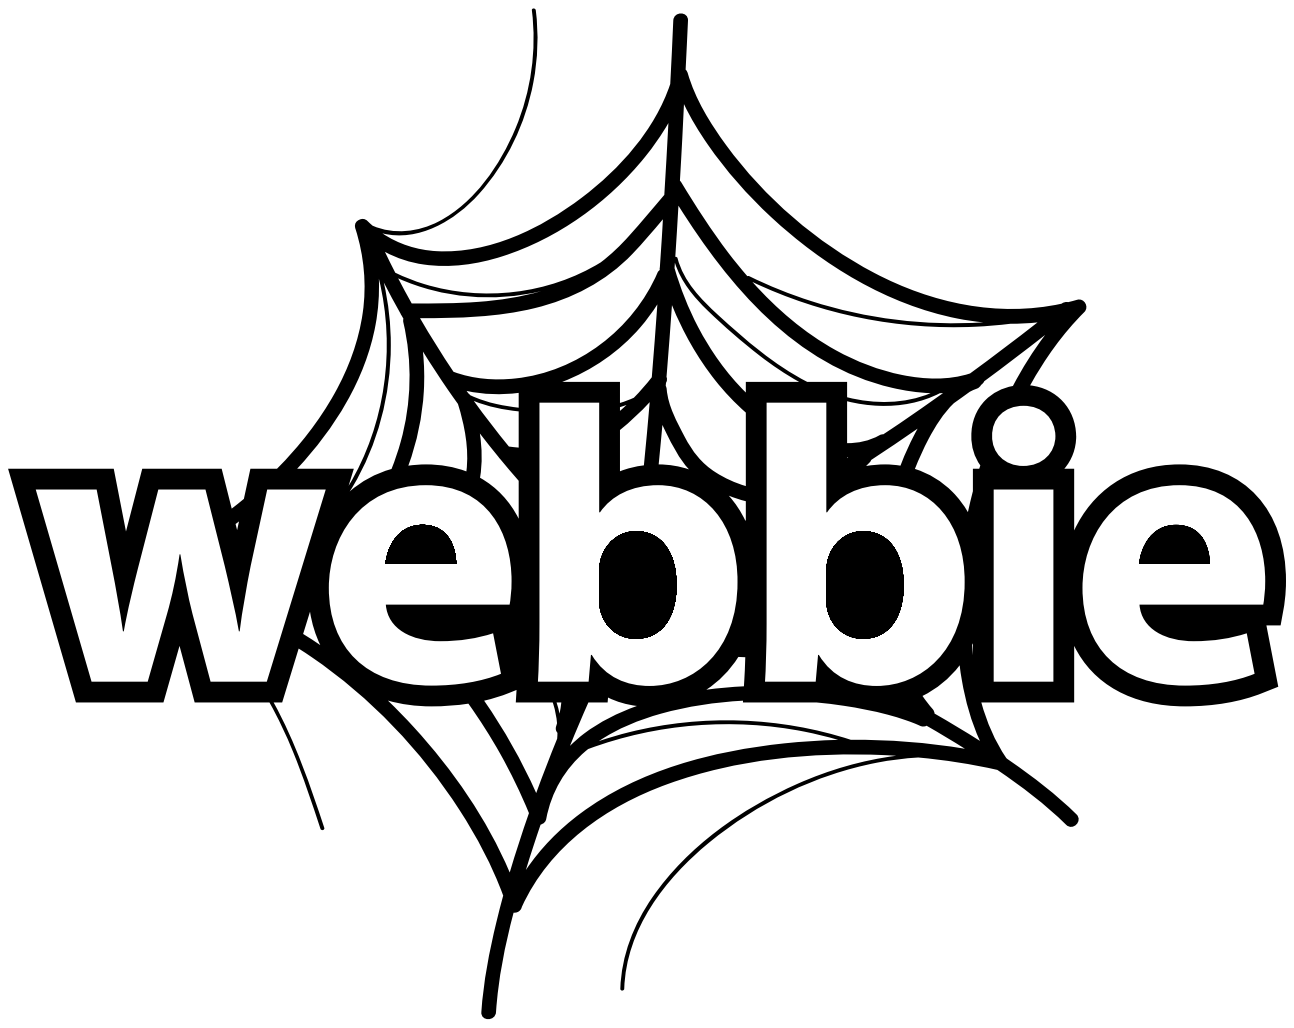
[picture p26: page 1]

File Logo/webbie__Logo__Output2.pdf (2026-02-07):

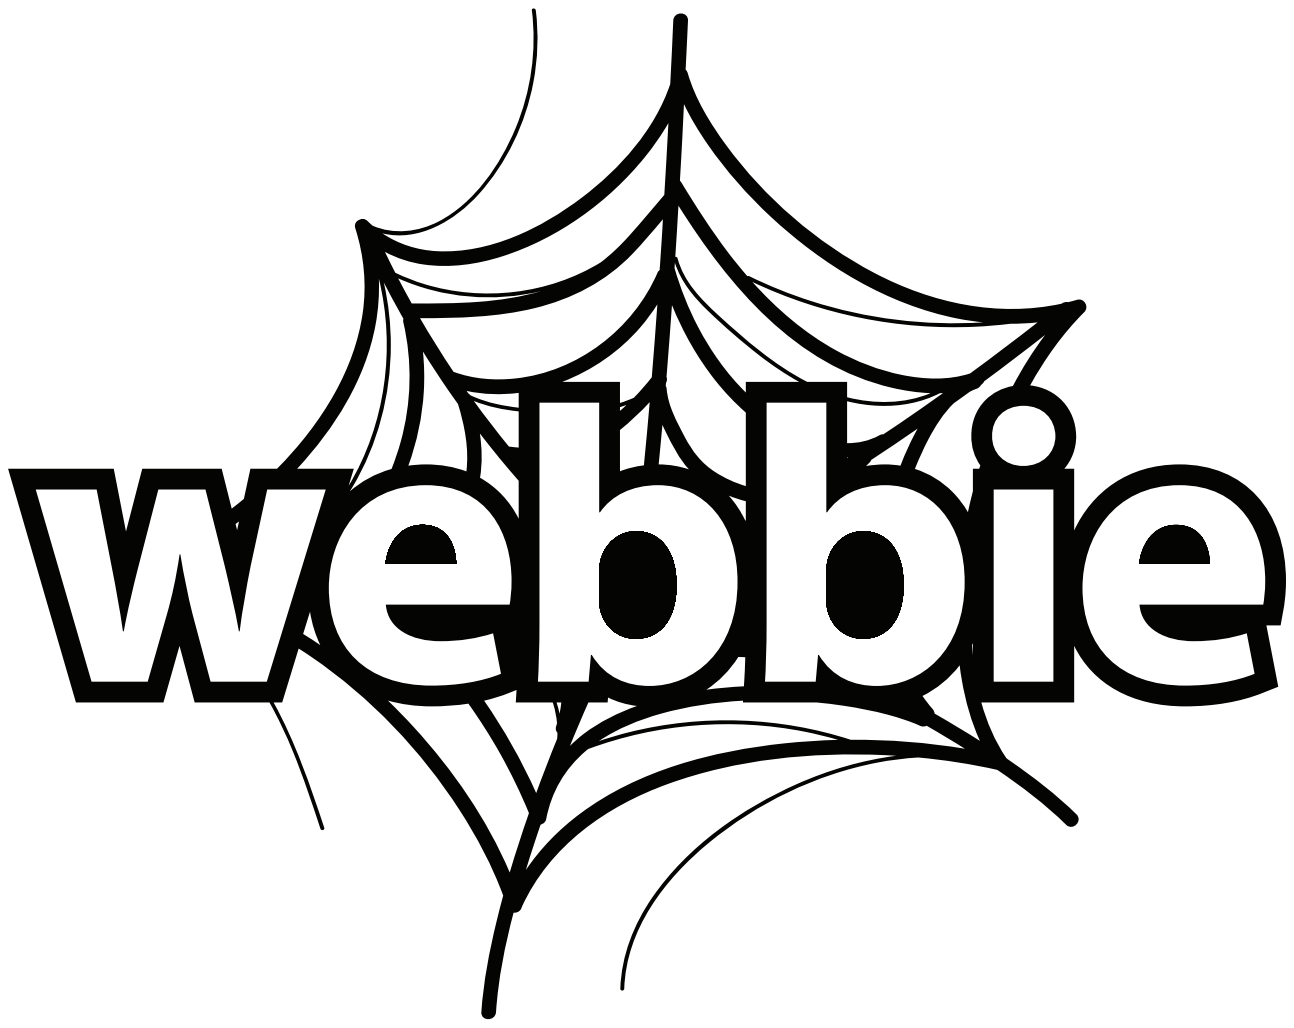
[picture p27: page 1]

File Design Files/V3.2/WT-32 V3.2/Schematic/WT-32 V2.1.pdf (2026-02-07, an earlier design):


470R RST Jumper in case issue with RST

Calculation done for 5.4V, after diode 5V

SIZE | | | REV

SCALE: | FILE NAME | SHEET OF 2


SIZE | | | REV

SCALE: | FILE NAME | SHEET OF 2


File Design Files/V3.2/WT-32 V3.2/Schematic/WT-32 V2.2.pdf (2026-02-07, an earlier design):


470R RST Jumper in case issue with RST

Calculation done for 5.4V, after diode 5V

SIZE | | | REV

SCALE: | FILE NAME | SHEET OF 2


SIZE | | | REV

SCALE: | FILE NAME | SHEET OF 2

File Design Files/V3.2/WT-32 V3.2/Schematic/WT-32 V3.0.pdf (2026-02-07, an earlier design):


SIZE | | | REV

SCALE: | FILE NAME | SHEET OF


SIZ E | | | RE V

SCA L E : | FIL E NA M E ntro l l er_Sh e et.Sc h D o c | SHE E T OF


SIZE | | | REV

SCALE: | FILE NAME | SHEET OF


SIZ E | | | RE V

SCA L E : | FIL E NA M E e l G a u g e _Sh e et.Sc h D o c | SHE E T OF
